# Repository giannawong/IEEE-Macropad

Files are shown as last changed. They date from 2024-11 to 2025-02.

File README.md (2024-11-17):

# IEEE-Macropad

**References & Inspiration:**
- [ai03 PCB Design Guide](https://wiki.ai03.com/books/pcb-design)
  - [MX Switch footprint library](https://github.com/ai03-2725/MX_Alps_Hybrid)
  - [Other keyboard parts library](https://github.com/ai03-2725/random-keyboard-parts.pretty)
- [tokaku - making an osu! keypad 𝒐𝒖𝒕 𝒐𝒇 𝒔𝒑𝒊𝒕𝒆 ⭐](https://youtu.be/amLrU65DACw?si=5710u0JO2Urghqpn)

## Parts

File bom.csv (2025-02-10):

Reference | Value | Datasheet | Footprint | Qty | DNP
C1,C2 | 22pF | ~ | Capacitor_SMD:C_0805_2012Metric | 2
C3 | 1uF | ~ | Capacitor_SMD:C_0805_2012Metric | 1
C4,C5,C6 | 0.1uF | ~ | Capacitor_SMD:C_0805_2012Metric | 3
C7 | 10uF | ~ | Capacitor_SMD:C_0805_2012Metric | 1
D1,D2,D3,D4,D5,D6,D7,D8,D9,D10,D11,D12,D13,D14,D15,D16 | SOD-123 | ~ | Diode_SMD:D_SOD-123 | 16
F1 | 500mA | ~ | Fuse:Fuse_1206_3216Metric | 1
MX1,MX2,MX3,MX4,MX5,MX6,MX7,MX8,MX9,MX10,MX11,MX12,MX13,MX14,MX15,MX16 | MX-NoLED |  | MX_Only:MXOnly-1U-NoLED | 16
R1,R4 | 10k | ~ | Resistor_SMD:R_0805_2012Metric | 2
R2,R3 | 22 | ~ | Resistor_SMD:R_0805_2012Metric | 2
SW1 | SW_Push | ~ | random-keyboard-parts:SKQG-1155865 | 1
U1 | ATmega32U4-A | http://ww1.microchip.com/downloads/en/DeviceDoc/Atmel-7766-8-bit-AVR-ATmega16U4-32U4_Datasheet.pdf | Package_QFP:TQFP-44_10x10mm_P0.8mm | 1
USB1 | Molex-0548190589 |  | random-keyboard-parts:Molex-0548190589 | 1
Y1 | 16MHz | ~ | Crystal:Crystal_SMD_3225-4Pin_3.2x2.5mm | 1

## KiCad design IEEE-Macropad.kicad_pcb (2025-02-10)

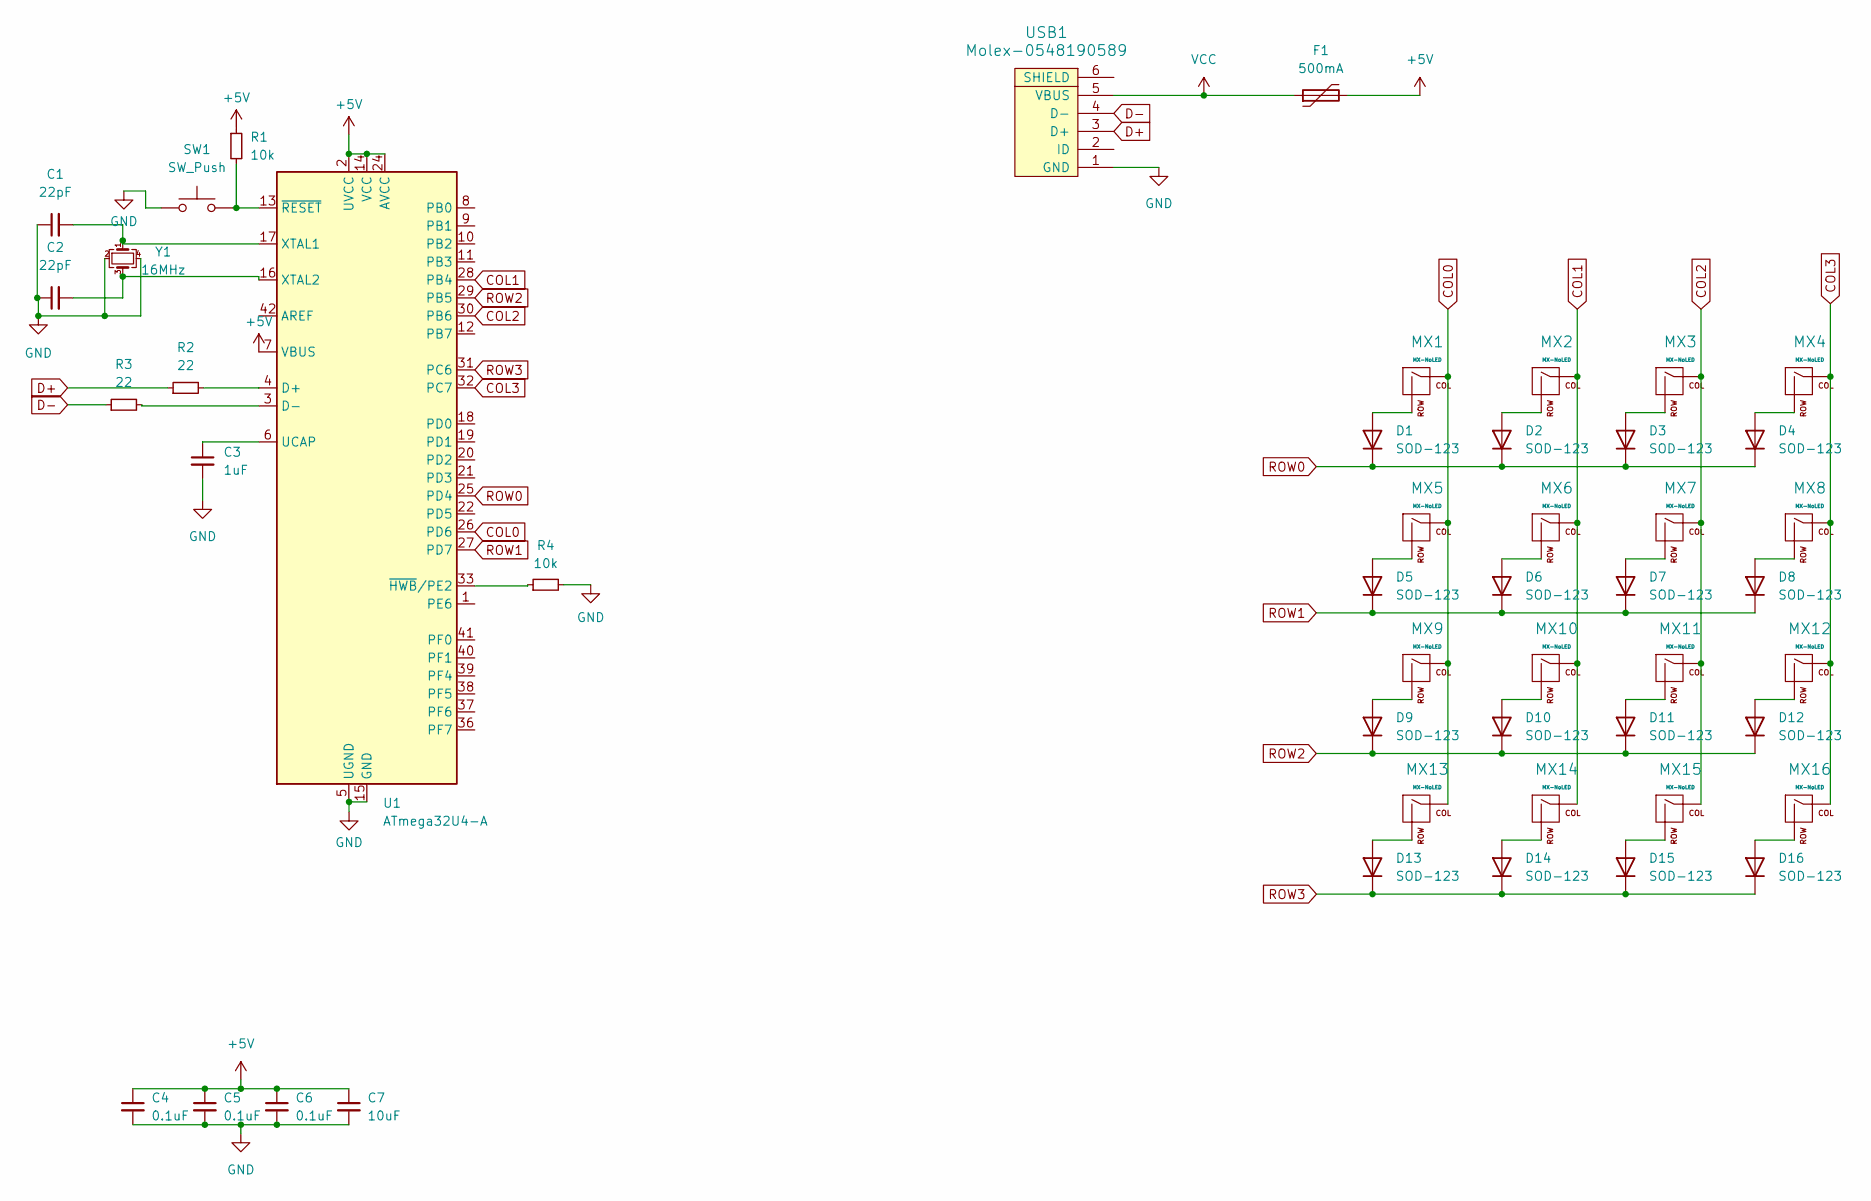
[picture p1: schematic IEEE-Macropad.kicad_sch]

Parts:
C1, C2: 22pF; C_0805_2012Metric
C3: 1uF; C_0805_2012Metric
C4, C5, C6: 0.1uF; C_0805_2012Metric
C7: 10uF; C_0805_2012Metric
D1, D2, D3, D4, D5, D6, D7, D8, D9, D10, D11, D12, D13, D14, D15, D16: SOD-123; D_SOD-123
F1: 500mA; Fuse_1206_3216Metric
MX1, MX2, MX3, MX4, MX5, MX6, MX7, MX8, MX9, MX10, MX11, MX12, MX13, MX14, MX15, MX16: MX-NoLED; MXOnly-1U-NoLED
R1, R4: 10k; R_0805_2012Metric
R2, R3: 22; R_0805_2012Metric
SW1: SW_Push; SKQG-1155865
U1: ATmega32U4-A; TQFP-44_10x10mm_P0.8mm
USB1: Molex-0548190589
Y1: 16MHz; Crystal_SMD_3225-4Pin_3.2x2.5mm

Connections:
+5V: C4.1, C5.1, C6.1, C7.1, F1.2, R1.1, U1.2 (UVCC), U1.7 (VBUS), U1.14 (VCC), U1.24 (AVCC), U1.34 (VCC), U1.44 (AVCC)
COL0: MX1.1 (COL), MX5.1 (COL), MX9.1 (COL), MX13.1 (COL), U1.26 (PD6)
COL1: MX2.1 (COL), MX6.1 (COL), MX10.1 (COL), MX14.1 (COL), U1.28 (PB4)
COL2: MX3.1 (COL), MX7.1 (COL), MX11.1 (COL), MX15.1 (COL), U1.30 (PB6)
COL3: MX4.1 (COL), MX8.1 (COL), MX12.1 (COL), MX16.1 (COL), U1.32 (PC7)
D+: R2.1, USB1.3 (D+)
D-: R3.1, USB1.4 (D-)
GND: C1.1, C2.1, C3.2, C4.2, C5.2, C6.2, C7.2, R4.2, SW1.1, U1.5 (UGND), U1.15 (GND), U1.23 (GND), U1.35 (GND), U1.43 (GND), USB1.1 (GND), Y1.2, Y1.4
unnamed: D1.2 (A), MX1.2 (ROW)
unnamed: D2.2 (A), MX2.2 (ROW)
unnamed: D3.2 (A), MX3.2 (ROW)
unnamed: D4.2 (A), MX4.2 (ROW)
unnamed: D5.2 (A), MX5.2 (ROW)
unnamed: D6.2 (A), MX6.2 (ROW)
unnamed: D7.2 (A), MX7.2 (ROW)
unnamed: D8.2 (A), MX8.2 (ROW)
unnamed: D9.2 (A), MX9.2 (ROW)
unnamed: D10.2 (A), MX10.2 (ROW)
unnamed: D11.2 (A), MX11.2 (ROW)
unnamed: D12.2 (A), MX12.2 (ROW)
unnamed: D13.2 (A), MX13.2 (ROW)
unnamed: D14.2 (A), MX14.2 (ROW)
unnamed: D15.2 (A), MX15.2 (ROW)
unnamed: D16.2 (A), MX16.2 (ROW)
unnamed: R2.2, U1.4 (D+)
unnamed: R3.2, U1.3 (D-)
unnamed: C3.1, U1.6 (UCAP)
unnamed: C1.2, U1.17 (XTAL1), Y1.1
unnamed: C2.2, U1.16 (XTAL2), Y1.3
unnamed: R4.1, U1.33 (~HWB/PE2)
unnamed: R1.2, SW1.2, U1.13 (~RESET)
ROW0: D1.1 (K), D2.1 (K), D3.1 (K), D4.1 (K), U1.25 (PD4)
ROW1: D5.1 (K), D6.1 (K), D7.1 (K), D8.1 (K), U1.27 (PD7)
ROW2: D9.1 (K), D10.1 (K), D11.1 (K), D12.1 (K), U1.29 (PB5)
ROW3: D13.1 (K), D14.1 (K), D15.1 (K), D16.1 (K), U1.31 (PC6)
VCC: F1.1, USB1.5 (VBUS)

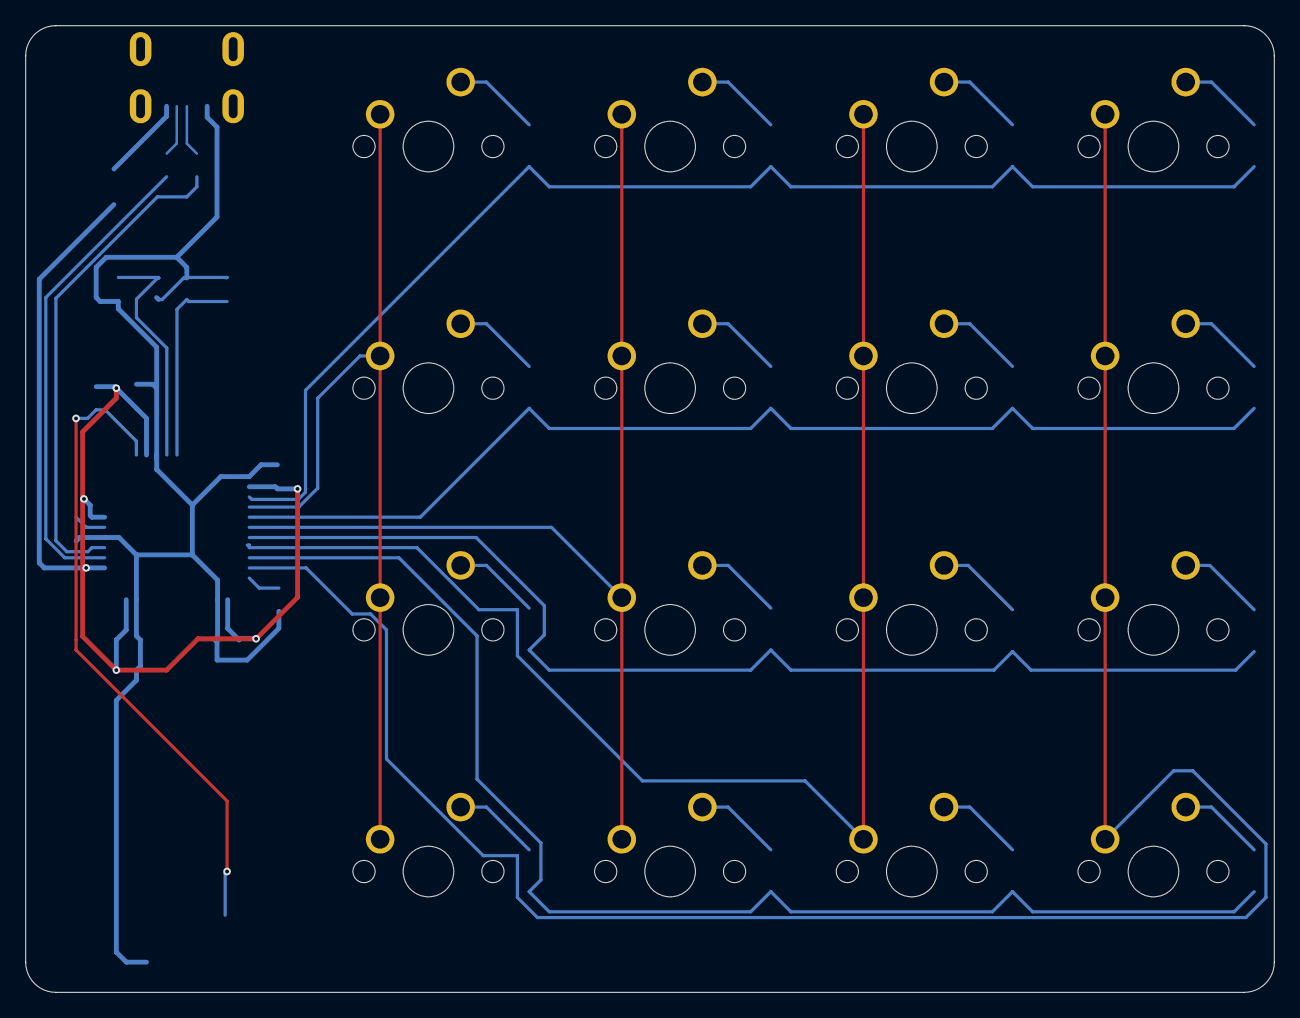
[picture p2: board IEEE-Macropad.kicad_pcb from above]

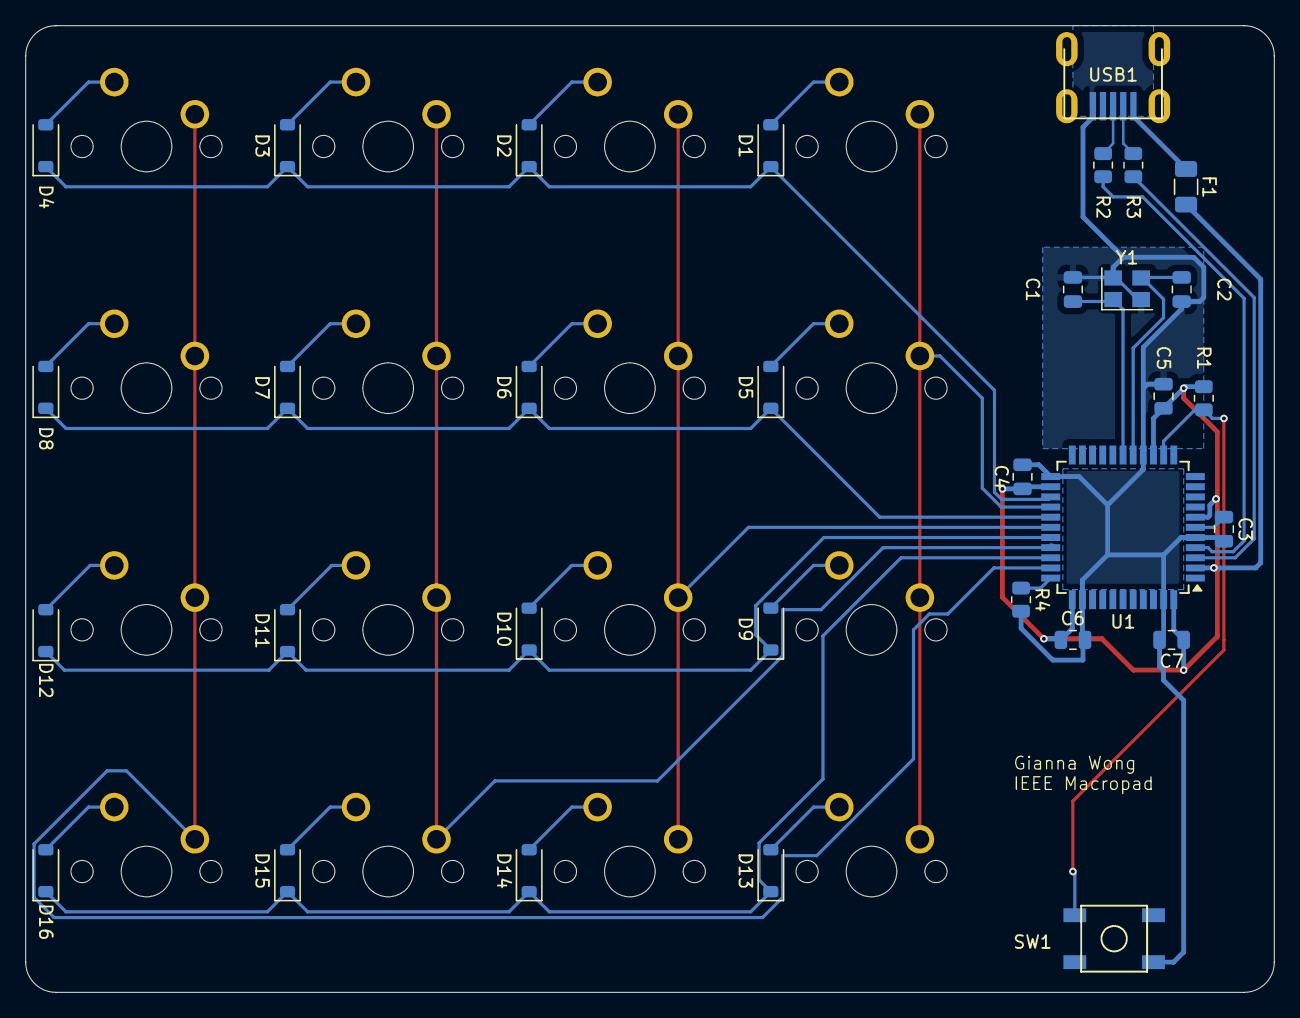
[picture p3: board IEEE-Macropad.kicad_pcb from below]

Board: 2 copper layers, 98.4 x 76.2 mm, 48 parts (32 on the bottom side), 36 nets.

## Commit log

2024-11-15 create kicad files
    [IEEE-Macropad.kicad_pcb, IEEE-Macropad.kicad_sch]
2024-11-15 add footprint libs
2024-11-17 finished pcb?
    [IEEE-Macropad.kicad_pcb, IEEE-Macropad.kicad_sch]
2024-11-17 fill zones
    [IEEE-Macropad.kicad_pcb]
2025-01-30 gerber files
    [IEEE-Macropad-B_Cu.gbr, IEEE-Macropad-B_Mask.gbr, IEEE-Macropad-B_Paste.gbr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]
2025-02-10 changed files
    [IEEE-Macropad.kicad_pcb, bom.csv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]
